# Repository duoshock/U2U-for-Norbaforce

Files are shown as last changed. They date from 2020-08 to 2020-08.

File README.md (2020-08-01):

#USB to USB for Norbaforce

This U2U is based on Hasu USB to USB with the rearranged component layout to fit Norbaforce housing. It's only compatible with Realforce R1 keyboard. However, It's easy to adapt it for Realforce R2 with the KiCad project.

QMK firmware is recommended - Enter DFU mode without having access to the physical rest switch with command keycode enable. (Although, there is a known issue of this port regarding not registering the board after computer reboot.)

Hasu U2U TMK firmware is also compatible.

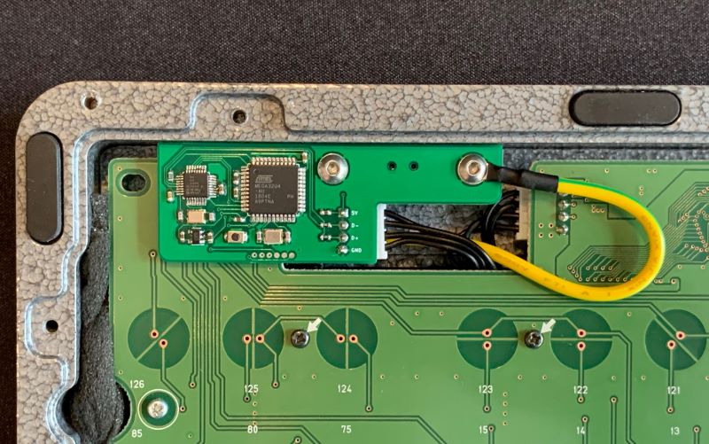
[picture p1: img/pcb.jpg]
PCB Snap


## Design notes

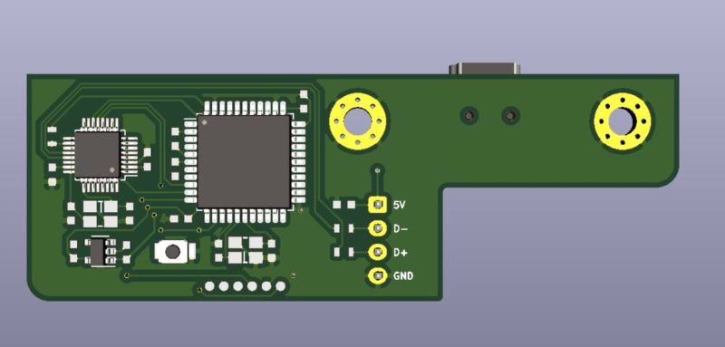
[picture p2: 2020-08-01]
img/pcb2.jpg

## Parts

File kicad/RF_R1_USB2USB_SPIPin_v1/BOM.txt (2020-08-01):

"Source:"	"M:\Miscellaneous\Keyboard\Realforce 91UDK-G\PCB\Project\RF_R1_USB2USB_SPIPin_v1\RF_R1_USB2USB_SPIPin_v1.sch"
"Date:"	"27/06/20 02:58:36"
"Tool:"	"Eeschema (5.1.4)-1"
"Component Count:"	"29"
"Ref"	"Value"	"Part"	"Footprint"	"Description"	"Vendor"
"C1"	"1u"	"keyboard_parts:C"	"Footprints:C_0603"	""	""
"C2"	"1u"	"keyboard_parts:C"	"Footprints:C_0603"	""	""
"C3"	"0.1u"	"keyboard_parts:C"	"Footprints:C_0603"	""	""
"C4"	"18p"	"keyboard_parts:C"	"Footprints:C_0603"	""	""
"C5"	"18p"	"keyboard_parts:C"	"Footprints:C_0603"	""	""
"C6"	"0.1u"	"keyboard_parts:C"	"Footprints:C_0603"	""	""
"C7"	"0.1u"	"keyboard_parts:C"	"Footprints:C_0603"	""	""
"C8"	"1u"	"keyboard_parts:C"	"Footprints:C_0603"	""	""
"C9"	"0.1u"	"keyboard_parts:C"	"Footprints:C_0603"	""	""
"C10"	"18p"	"keyboard_parts:C"	"Footprints:C_0603"	""	""
"C11"	"18p"	"keyboard_parts:C"	"Footprints:C_0603"	""	""
"C12"	"1u"	"keyboard_parts:C"	"Footprints:C_0603"	""	""
"C13"	"1u"	"keyboard_parts:C"	"Footprints:C_0603"	""	""
"J1"	"USB_B"	"keyboard_parts:USB_B"	"Connector_USB:USB_Mini-B_Lumberg_2486_01_Horizontal"	""	""
"J2"	"Conn_01x04"	"Connector_Generic:Conn_01x04"	"Connector_JST:JST_EH_S4B-EH_1x04_P2.50mm_Horizontal"	"Generic connector, single row, 01x04, script generated (kicad-library-utils/schlib/autogen/connector/)"	""
"J3"	"Earth"	"Connector_Generic:Conn_01x01"	"MountingHole:MountingHole_3mm_Pad_Via"	"Generic connector, single row, 01x01, script generated (kicad-library-utils/schlib/autogen/connector/)"	""
"J4"	"Earth"	"Connector_Generic:Conn_01x01"	"MountingHole:MountingHole_3mm_Pad_Via"	"Generic connector, single row, 01x01, script generated (kicad-library-utils/schlib/autogen/connector/)"	""
"P1"	"SPI pins"	"Connector_Generic:Conn_01x06"	"Footprints:Test Point 1mm x 6"	"Generic connector, single row, 01x06, script generated (kicad-library-utils/schlib/autogen/connector/)"	""
"R1"	"22"	"keyboard_parts:R"	"Footprints:R_0603"	""	""
"R2"	"22"	"keyboard_parts:R"	"Footprints:R_0603"	""	""
"R4"	"33"	"keyboard_parts:R"	"Footprints:R_0603"	""	""
"R5"	"33"	"keyboard_parts:R"	"Footprints:R_0603"	""	""
"R6"	"2K2"	"keyboard_parts:R"	"Footprints:R_0603"	""	""
"SW1"	"SW_PUSH"	"keyboard_parts:SW_PUSH"	"Footprints:SW_SPST_B3U-1000P"	""	""
"U1"	"ATMEGA32U4"	"keyboard_parts:ATMEGA32U4"	"Package_QFP:LQFP-44_10x10mm_P0.8mm"	""	""
"U2"	"MAX3421E"	"keyboard_parts:MAX3421E"	"Package_QFP:LQFP-32_5x5mm_P0.5mm"	""	""
"U3"	"MIC5504-3.3"	"keyboard_parts:LDO_REGULATOR"	"Package_TO_SOT_SMD:SOT-23-5"	"HOLTEK setup DC/DC converter"	""
"X1"	"16Mhz"	"keyboard_parts:XTAL_GND"	"Footprints:Crystal_FA238-TSX3225"	""	""
"X2"	"12Mhz"	"keyboard_parts:XTAL_GND"	"Footprints:Crystal_FA238-TSX3225"	""	""

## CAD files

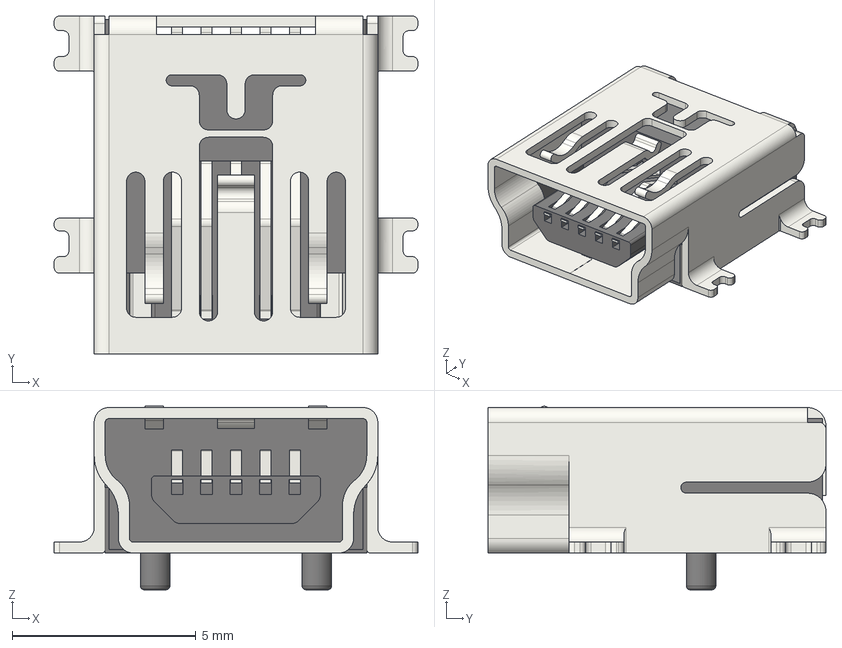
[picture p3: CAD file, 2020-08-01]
kicad/RF_R1_USB2USB_SPIPin_v1/shapes3D/USB_Mini-B_Lumberg_2486_01_Horizontal.step
9.90 x 9.20 x 5.00 mm

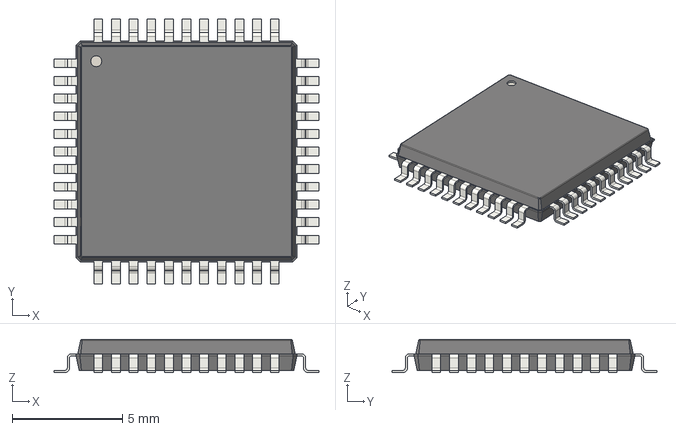
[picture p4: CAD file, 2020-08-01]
kicad/RF_R1_USB2USB_SPIPin_v1/shapes3D/LQFP-44_10x10mm_P0.8mm.step
12.0 x 12.0 x 1.50 mm

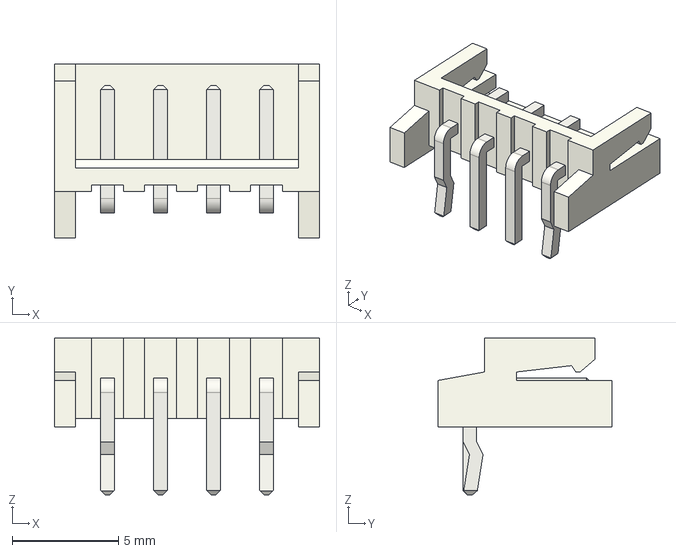
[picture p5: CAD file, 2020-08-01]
kicad/RF_R1_USB2USB_SPIPin_v1/shapes3D/JST_EH_S4B-EH_1x04_P2.50mm_Horizontal.step
12.5 x 8.20 x 7.40 mm

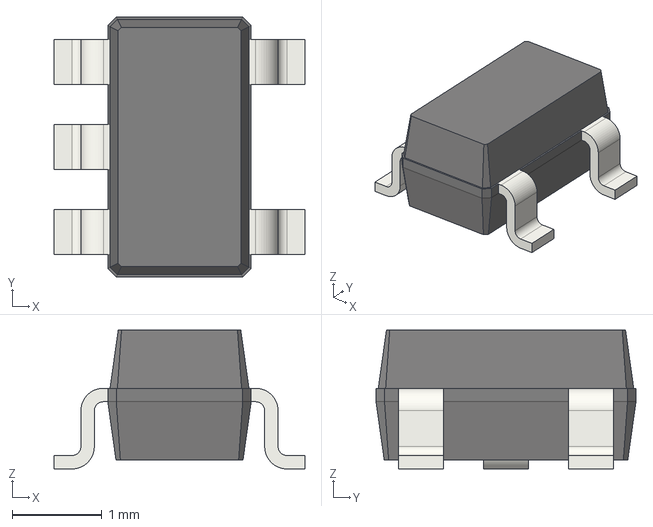
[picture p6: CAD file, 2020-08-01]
kicad/RF_R1_USB2USB_SPIPin_v1/shapes3D/SOT-23-5.step
2.80 x 2.90 x 1.55 mm

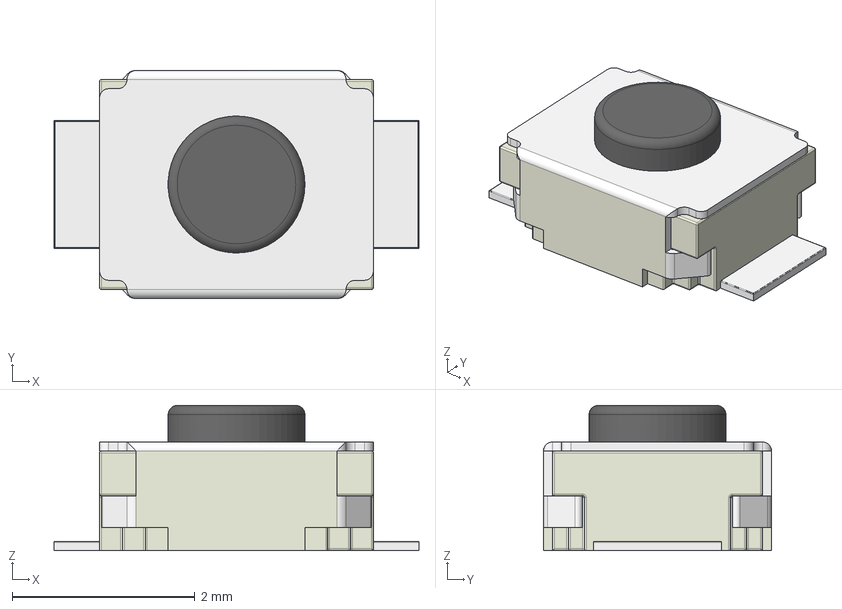
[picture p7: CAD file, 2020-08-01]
kicad/RF_R1_USB2USB_SPIPin_v1/shapes3D/SW_SPST_B3U-1000P.step
4.00 x 2.50 x 1.59 mm

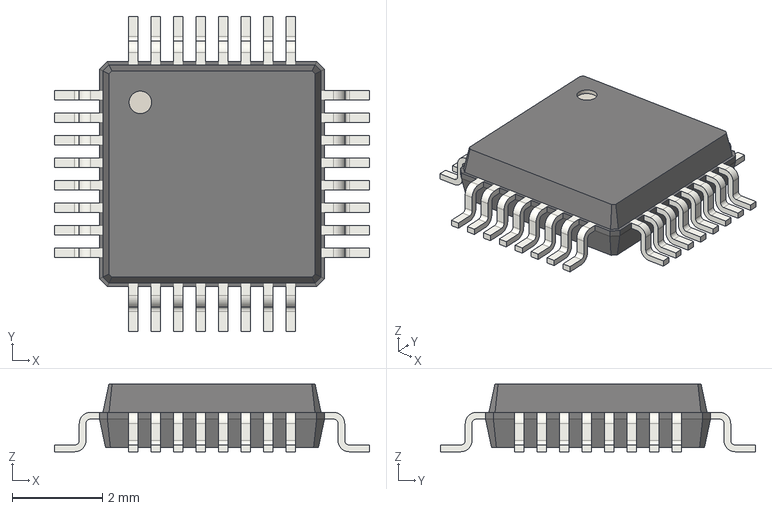
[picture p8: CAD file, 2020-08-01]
kicad/RF_R1_USB2USB_SPIPin_v1/shapes3D/LQFP-32_5x5mm_P0.5mm.step
7.00 x 7.00 x 1.50 mm

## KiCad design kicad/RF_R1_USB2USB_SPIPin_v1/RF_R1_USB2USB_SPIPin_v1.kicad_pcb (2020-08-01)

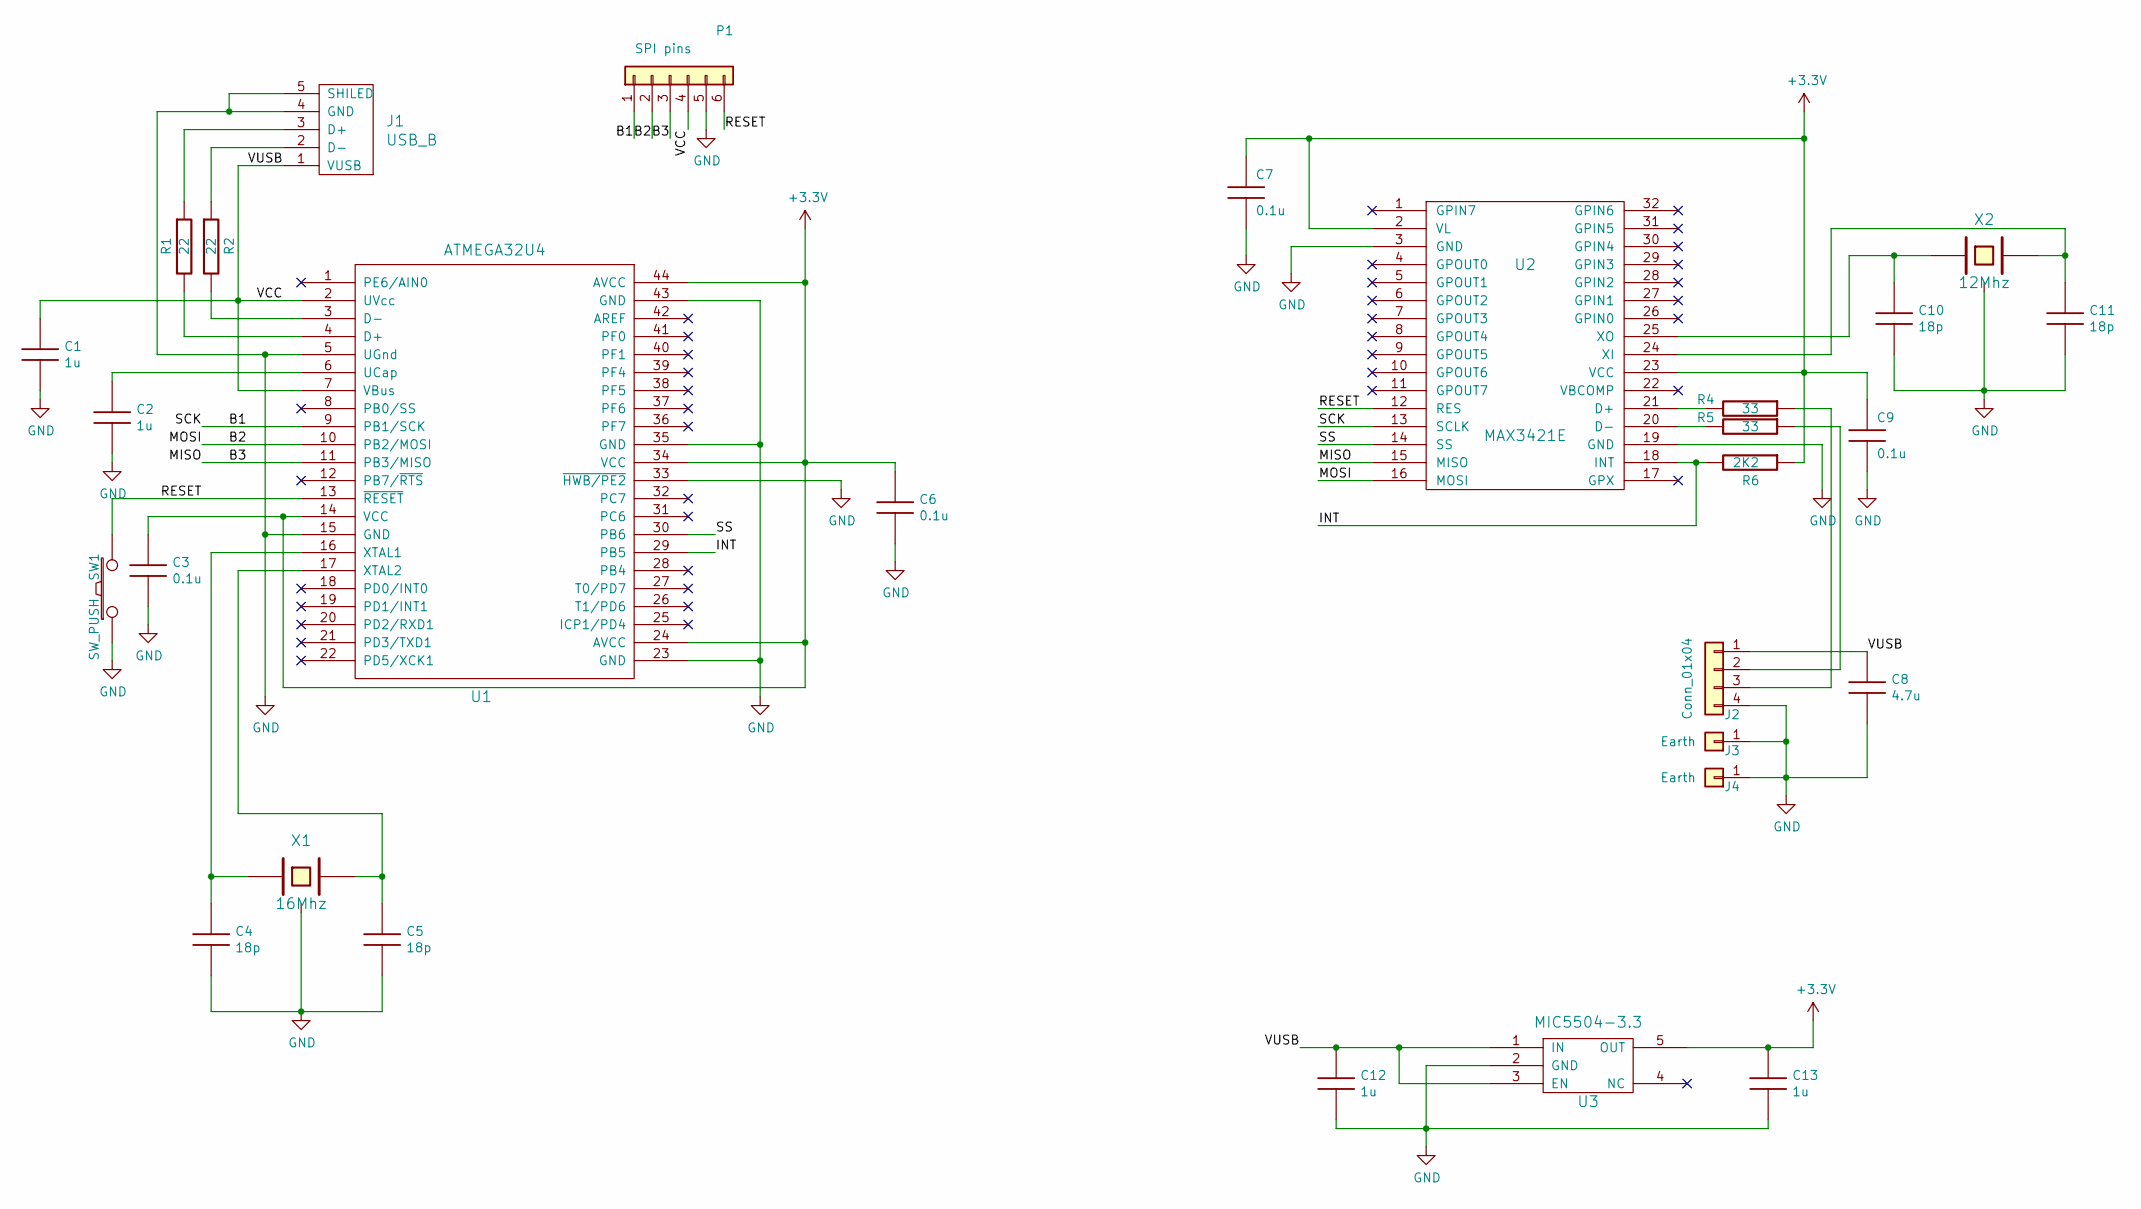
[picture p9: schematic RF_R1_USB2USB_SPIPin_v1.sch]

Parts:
C1, C2, C12, C13: 1u; C_0603
C3, C6, C7, C9: 0.1u; C_0603
C4, C5, C10, C11: 18p; C_0603
C8: 4.7u; C_0603
J1: USB_B; USB_Mini-B_Lumberg_2486_01_Horizontal
J2: Conn_01x04; JST_EH_S4B-EH_1x04_P2.50mm_Horizontal
J3, J4: Earth; MountingHole_3mm_Pad_Via
P1: SPI pins; Test Point 1mm x 6
R1, R2: 22; R_0603
R4, R5: 33; R_0603
R6: 2K2; R_0603
SW1: SW_PUSH; SW_SPST_B3U-1000P
U1: ATMEGA32U4; LQFP-44_10x10mm_P0.8mm
U2: MAX3421E; LQFP-32_5x5mm_P0.5mm
U3: MIC5504-3.3; SOT-23-5
X1: 16Mhz; Crystal_FA238-TSX3225
X2: 12Mhz; Crystal_FA238-TSX3225

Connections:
+3V3: C3.1, C6.1, C7.1, C9.1, C13.1, R6.1, U1.14 (VCC), U1.24 (AVCC), U1.34 (VCC), U1.44 (AVCC), U2.2 (VL), U2.23 (VCC), U3.5 (OUT)
/B1: P1.1, U1.9 (PB1/SCK), U2.13 (SCLK)
/B2: P1.2, U1.10 (PB2/MOSI), U2.16 (MOSI)
/B3: P1.3, U1.11 (PB3/MISO), U2.15 (MISO)
/INT: R6.2, U1.29 (PB5), U2.18 (INT)
/RESET: P1.6, SW1.2, U1.13 (~RESET), U2.12 (RES)
/SS: U1.30 (PB6), U2.14 (SS)
/VCC: C1.1, C8.1, C12.1, J1.1 (VUSB), J2.1, P1.4, U1.2 (UVcc), U1.7 (VBus), U3.1 (IN), U3.3 (EN)
GND: C1.2, C2.2, C3.2, C4.2, C5.2, C6.2, C7.2, C8.2, C9.2, C10.2, C11.2, C12.2, C13.2, J1.4 (GND), J1.5 (SHILED), J2.4, J3.1, J4.1, P1.5, SW1.1, U1.5 (UGnd), U1.15 (GND), U1.23 (GND), U1.33 (~HWB/PE2), U1.35 (GND), U1.43 (GND), U2.3 (GND), U2.19 (GND), U3.2 (GND), X1.3, X2.3
unnamed: C2.1, U1.6 (UCap)
unnamed: C4.1, U1.16 (XTAL1), X1.1
unnamed: C5.1, U1.17 (XTAL2), X1.2
unnamed: C10.1, U2.25 (XO), X2.1
unnamed: C11.1, U2.24 (XI), X2.2
unnamed: J1.2 (D-), R2.1
unnamed: J1.3 (D+), R1.1
unnamed: J2.2, R5.1
unnamed: J2.3, R4.1
unnamed: R1.2, U1.4 (D+)
unnamed: R2.2, U1.3 (D-)
unnamed: R4.2, U2.21 (D+)
unnamed: R5.2, U2.20 (D-)

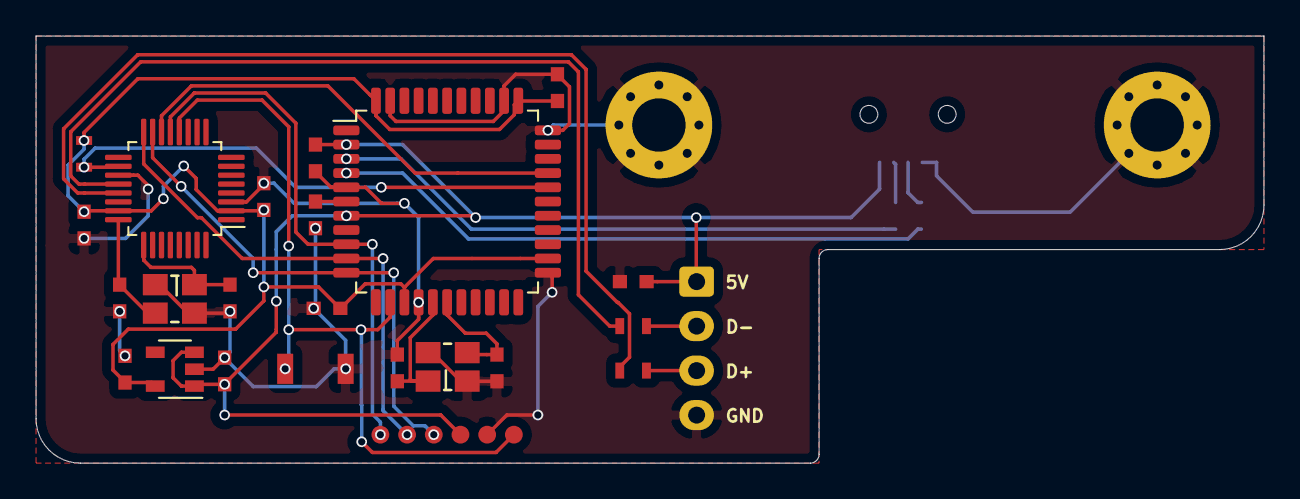
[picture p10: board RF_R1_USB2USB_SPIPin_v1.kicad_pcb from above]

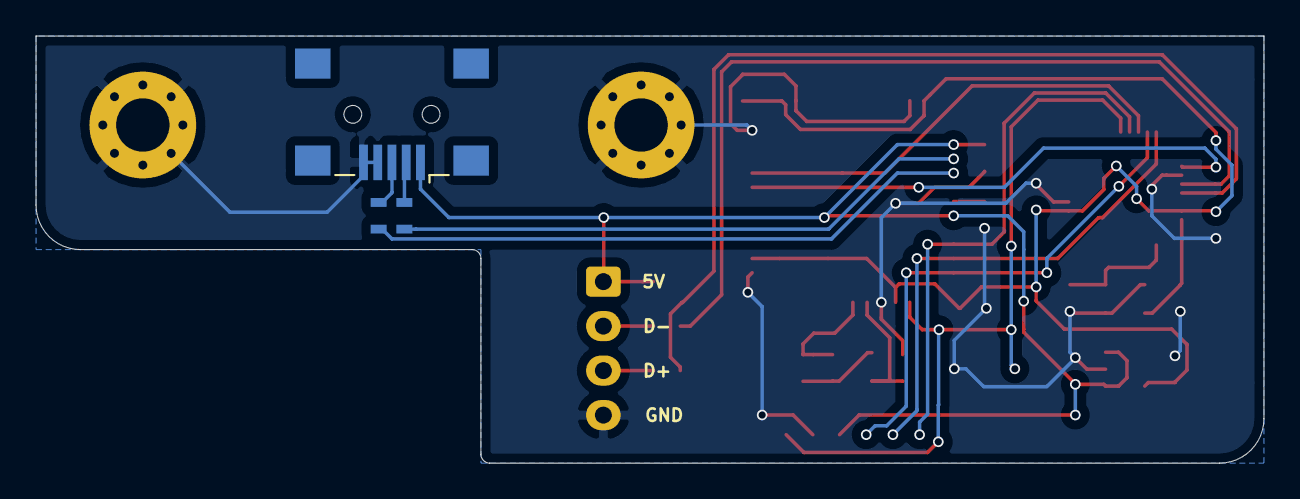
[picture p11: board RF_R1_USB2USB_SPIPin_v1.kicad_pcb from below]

Board: 2 copper layers, 69.0 x 24.0 mm, 29 parts (4 on the bottom side), 22 nets.

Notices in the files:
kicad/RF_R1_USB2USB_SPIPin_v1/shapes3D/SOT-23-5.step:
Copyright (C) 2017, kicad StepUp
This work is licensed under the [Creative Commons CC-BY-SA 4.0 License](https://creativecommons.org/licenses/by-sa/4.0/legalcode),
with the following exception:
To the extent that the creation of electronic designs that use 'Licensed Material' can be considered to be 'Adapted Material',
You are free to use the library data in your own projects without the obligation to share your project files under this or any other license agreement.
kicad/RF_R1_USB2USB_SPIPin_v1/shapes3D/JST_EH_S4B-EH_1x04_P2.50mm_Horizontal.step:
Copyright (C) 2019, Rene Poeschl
